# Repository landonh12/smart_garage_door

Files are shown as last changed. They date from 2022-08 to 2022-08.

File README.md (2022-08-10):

# Smart Garage Door Controller

This is a PCB made to house a NodeMCU-ESP32S to control my Genie Garage Door. It replaces the wall controller that was installed when we purchased the home.

The original circuit was simple - short RED and WHITE wires to open and close the door, and divide the voltage between RED and WHITE to toggle the garage light.

I used FETs for this - RFP30N06LEs to be exact. The board also supports STD26P3LLH6 FETs.

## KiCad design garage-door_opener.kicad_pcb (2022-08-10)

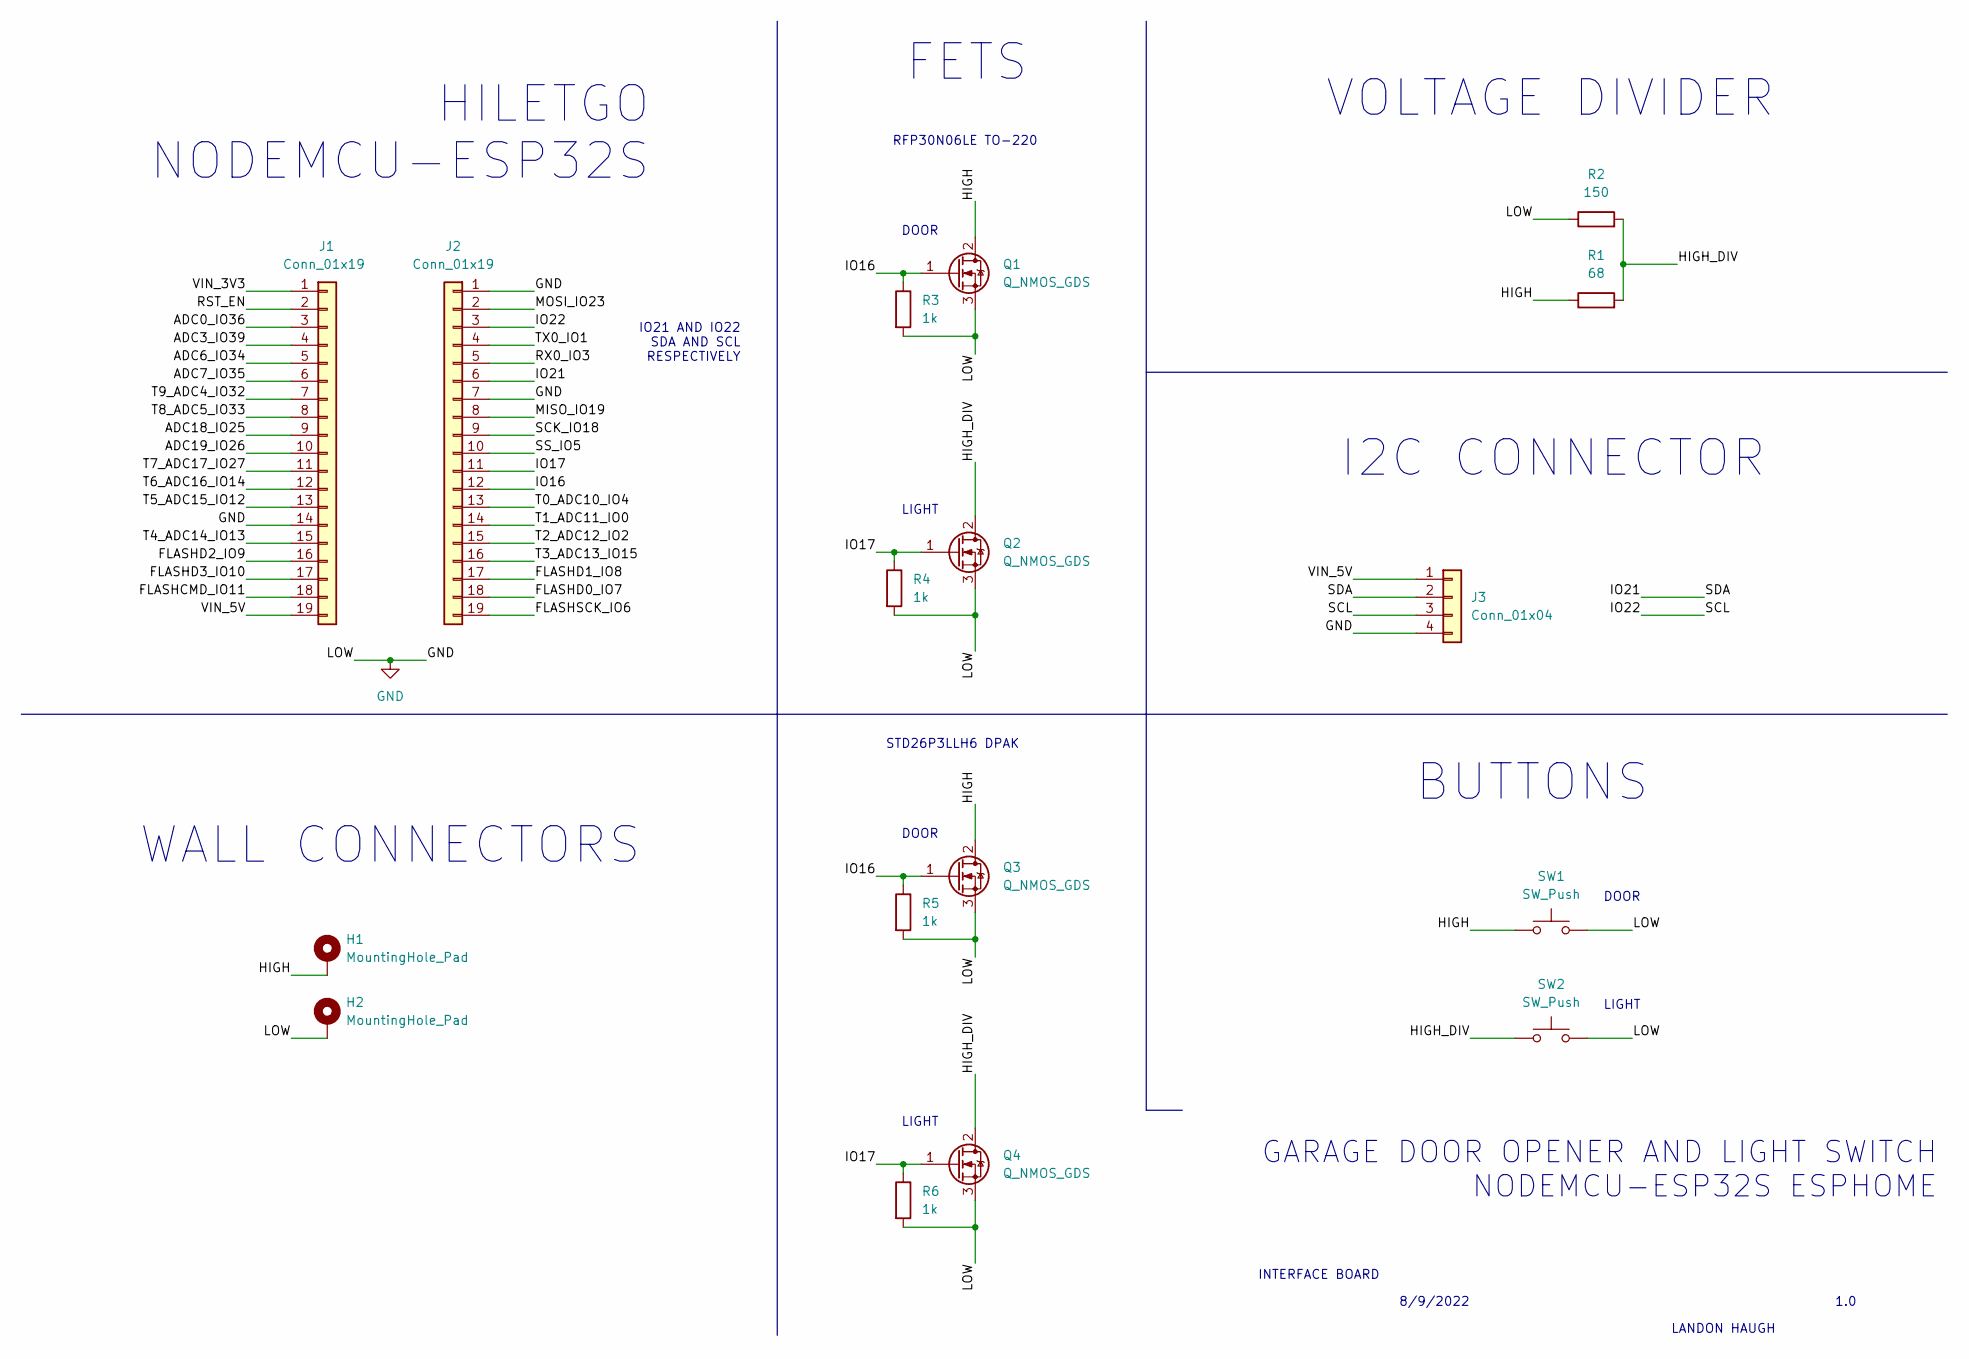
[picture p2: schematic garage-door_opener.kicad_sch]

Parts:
H1, H2: MountingHole_Pad; MountingHole_3.2mm_M3_DIN965_Pad_TopBottom
J1, J2: Conn_01x19; PinHeader_1x19_P2.54mm_Vertical
J3: Conn_01x04; PinHeader_1x04_P2.54mm_Vertical
Q1, Q2: Q_NMOS_GDS; TO-220-3_Horizontal_TabDown
Q3, Q4: Q_NMOS_GDS; TO-252-2
R1: 68; R_Axial_DIN0207_L6.3mm_D2.5mm_P10.16mm_Horizontal
R2: 150; R_Axial_DIN0207_L6.3mm_D2.5mm_P10.16mm_Horizontal
R3, R4, R5, R6: 1k; R_Axial_DIN0207_L6.3mm_D2.5mm_P10.16mm_Horizontal
SW1, SW2: SW_Push; SW_PUSH-12mm

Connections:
/ADC0_IO36: J1.3
/ADC3_IO39: J1.4
/ADC6_IO34: J1.5
/ADC7_IO35: J1.6
/ADC18_IO25: J1.9
/ADC19_IO26: J1.10
/FLASHCMD_IO11: J1.18
/FLASHD0_IO7: J2.18
/FLASHD1_IO8: J2.17
/FLASHD2_IO9: J1.16
/FLASHD3_IO10: J1.17
/FLASHSCK_IO6: J2.19
/HIGH: H1.1, Q1.2 (D), Q3.2 (D), R1.1, SW1.1
/HIGH_DIV: Q2.2 (D), Q4.2 (D), R1.2, R2.2, SW2.1
/IO16: J2.12, Q1.1 (G), Q3.1 (G), R3.1, R5.1
/IO17: J2.11, Q2.1 (G), Q4.1 (G), R4.1, R6.1
/IO21: J2.6, J3.2
/IO22: J2.3, J3.3
/MISO_IO19: J2.8
/MOSI_IO23: J2.2
/RST_EN: J1.2
/RX0_IO3: J2.5
/SCK_IO18: J2.9
/SS_IO5: J2.10
/T0_ADC10_IO4: J2.13
/T1_ADC11_IO0: J2.14
/T2_ADC12_IO2: J2.15
/T3_ADC13_IO15: J2.16
/T4_ADC14_IO13: J1.15
/T5_ADC15_IO12: J1.13
/T6_ADC16_IO14: J1.12
/T7_ADC17_IO27: J1.11
/T8_ADC5_IO33: J1.8
/T9_ADC4_IO32: J1.7
/TX0_IO1: J2.4
/VIN_3V3: J1.1
/VIN_5V: J1.19, J3.1
GND: H2.1, J1.14, J2.1, J2.7, J3.4, Q1.3 (S), Q2.3 (S), Q3.3 (S), Q4.3 (S), R2.1, R3.2, R4.2, R5.2, R6.2, SW1.2, SW2.2

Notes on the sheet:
VOLTAGE DIVIDER
WALL CONNECTORS
LANDON HAUGH
DOOR
IO21 AND IO22 SDA AND SCL RESPECTIVELY
HILETGO NODEMCU-ESP32S
LIGHT
INTERFACE BOARD
STD26P3LLH6 DPAK
1.0
RFP30N06LE TO-220
I2C CONNECTOR
GARAGE DOOR OPENER AND LIGHT SWITCH NODEMCU-ESP32S ESPHOME
FETS
BUTTONS
8/9/2022

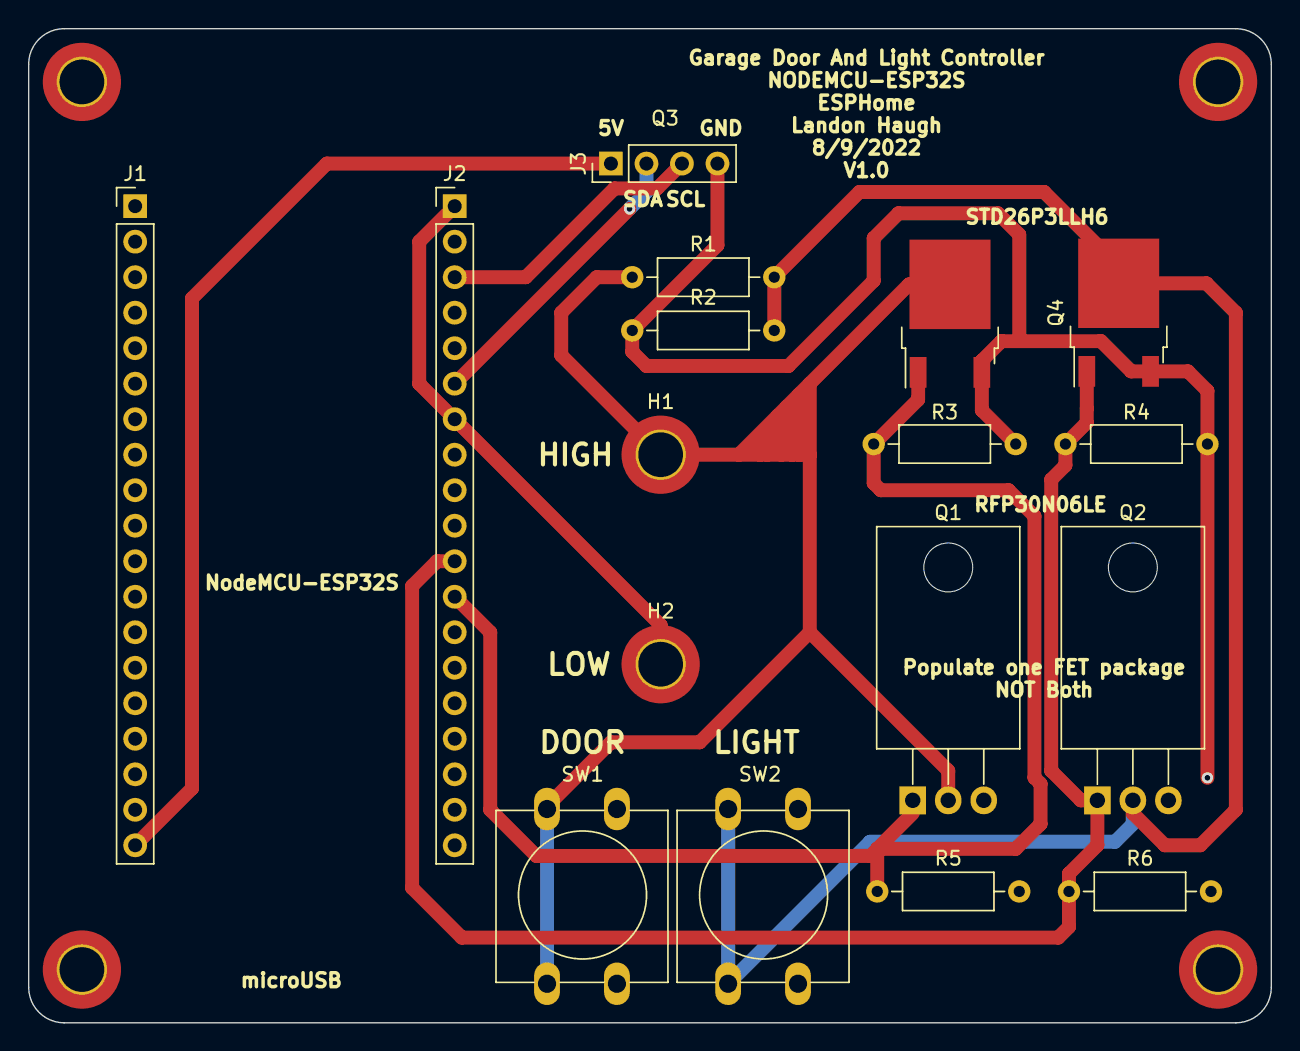
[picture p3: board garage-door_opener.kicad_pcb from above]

Board: 2 copper layers, 88.9 x 71.1 mm, 19 parts (0 on the bottom side), 8 nets.

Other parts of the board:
mnt: MountingHole_3.2mm_M3_DIN965_Pad_TopBottom
mnt#2: MountingHole_3.2mm_M3_DIN965_Pad_TopBottom
